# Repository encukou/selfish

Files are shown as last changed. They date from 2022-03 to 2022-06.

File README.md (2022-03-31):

# Selfish keyboard

This is an experiment.

Selfish layout for Moonlander is [here](https://configure.zsa.io/moonlander/layouts/DapMK/latest/0),
or, with some tweaks the configurator can't do, in [my QMK fork](https://github.com/encukou/qmk_firmware/blob/selfish/keyboards/moonlander/keymaps/selfish/keymap.c).

## Thanks

Thank you to Peter Lyons for sharing
[Squeezebox](https://peterlyons.com/problog/2022/01/squeezebox-keyboard-v2112/)!

## Legal stuff

Any file in this repository may be used either under the MIT licence or the
CC-BY-SA-40 licence, at your choice.
Please link to https://github.com/encukou/selfish for attribution.

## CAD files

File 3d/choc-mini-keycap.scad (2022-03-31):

OFFCENTER = 0;  // [-2.5:.1:2.5]

module _end_customizer () {}

CAP_SIZE = 12.5;
TOP_HEIGHT = 2;
CURVE_IN = 1;
STEM_BASE = 0.25;
STEM_CYLOUT = 0.2;

BORDER_W = 0.4;
BORDER_H = 0.25;

EPS = 0.001;
INF = 100;
$fn = 50;

module box (sizes, centering=[1, 1, 1], extra_negative=[0, 0, 0]) {
    translate ([
        -sizes[0]*centering[0]/2-extra_negative[0],
        -sizes[1]*centering[1]/2-extra_negative[1],
        -sizes[2]*centering[2]/2-extra_negative[2],
    ]) {
        cube ([
            sizes[0]+extra_negative[0],
            sizes[1]+extra_negative[1],
            sizes[2]+extra_negative[2],
        ]);
    }
}

module round_slab (dims, r, rd=0) {
    w = dims[0];
    h = dims[1];
    d = dims[2];
    if (r <= rd) {
        box ([w, h, d], [1, 1, 0]);
    } else {
        hull () for (x=[-1,1]) for (y=[-1,1]) scale ([x, y, 1]) {
            translate ([w/2-r, h/2-r, 0]) cylinder (d, r=r-rd);
        }
    }
}

// x^2 + diag^2 = (x+CURVE_IN)²
function cdist (base, inset) = (base^2 - inset^2) / (2 * inset);

rotate ([90, 0, 0]) union () {
    translate ([0, 0, -EPS]) difference () {
        // Main body
        hull () for (x=[-1,1]) for (y=[-1,1]) scale ([x, y, 1]) {
            fillet = TOP_HEIGHT;
            r = TOP_HEIGHT/2;
            disp = CAP_SIZE / 2 - r - r/sqrt(2);
            translate ([disp, disp, 0]) {
                rotate ([0, 0, 45]) rotate ([90, 0, 0]) {
                    rotate_extrude (angle=90) {
                        translate ([r, 0, 0]) circle (r=r);
                    }
                }
            }
        }

        // Spherical groove
        diag = sqrt(2) * CAP_SIZE/2;
        x = cdist(diag, CURVE_IN);
        intersection () {
            translate ([0, 0, x + TOP_HEIGHT]) rotate ([90, 0, 0]) {
                sphere (r=(x+CURVE_IN), $fn=300);
            }
            box ([CAP_SIZE, CAP_SIZE, TOP_HEIGHT+EPS], [1, 1, 0]);
        }
    }
    // Stem
    translate ([0, OFFCENTER, 0]) scale ([1, 1, -1]) {
        hull () {
            box ([10, 4.5, EPS], [1, 1, 0]);
            box ([10-STEM_BASE*2, 4.5-STEM_BASE*2, STEM_BASE], [1, 1, 0]);
        }
        // Stem legs
        for (x=[-1, 1]) scale ([x, 1, 1]) translate ([2.85, 0, 0]) {
            xsz = 0.95 - /* tolerance */ 0.15;
            ysz = 2.75;
            zsz = 3.9+STEM_BASE;
            w = cdist(ysz/4, STEM_CYLOUT);
            box ([xsz, ysz, zsz], [1, 1, 0]);
            for (r=[-1,1]) scale ([r, r, 1]) intersection () {
                translate ([-xsz/2, 0, 0]) box ([INF, INF, INF], [2, 1, 1]);
                translate ([w-xsz/2, ysz/4, 0]) {
                    cylinder (zsz, r=w+STEM_CYLOUT);
                }
            }
        }
    }
    // Rim
    scale ([1, 1, -1]) {
        r = TOP_HEIGHT/2;
        difference () {
            round_slab ([CAP_SIZE, CAP_SIZE, BORDER_H], r);
            hull () {
                sz = CAP_SIZE - BORDER_W;
                round_slab ([CAP_SIZE, CAP_SIZE, EPS], r, BORDER_W * 1.75);
                translate ([0, 0, BORDER_H+EPS]) {
                    round_slab ([CAP_SIZE, CAP_SIZE, EPS], r, BORDER_W);
                }
            }
        }
    }
}

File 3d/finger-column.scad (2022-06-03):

// Upper row angle
angle1 = 30;  // [20:30]
// Lower row angle
angle2 = 80;  // [20:95]
// Middle row angle (i.e. mounting tab angle)
TAB_ANGLE = 17.5; // [-60:60]

assert (angle2 - TAB_ANGLE <= 95, "Middle row angle too negative");

// Color for switch preview
SWITCH_COLOR = [.5, .3, 0];

module _end_customizer () {}

CHOC_SZ = 13.80;
CHOC_FULL_SZ = 15.00;
CHOC_H = 2.20;
WELL_ANGLES = [angle1, angle2];
CAP_SPACE = 13;
KEY_DEPTH = 10.5;

BOX_SZ_X = 15;
BOX_SZ_Y = 16;

BOTTOM_WALL = 1;

WIRE_R = .5;  // CHECK!
WIRE_N = 2;
WIRE_ORG_T = 1;
WIRE_ORG_W = 2;

DIODEW_R = 0.3;

// M3 screws
SCREW_R = 3/2;

TOL = 0.25;
RTOL = TOL/2;

INF = 22;
EPS = 0.01;

$fn = 50;

WALL_H = CHOC_H+BOTTOM_WALL;

module box (sizes, centering=[1, 1, 1], extra_negative=[0, 0, 0]) {
    translate ([
        -sizes[0]*centering[0]/2-extra_negative[0],
        -sizes[1]*centering[1]/2-extra_negative[1],
        -sizes[2]*centering[2]/2-extra_negative[2],
    ]) {
        cube ([
            sizes[0]+extra_negative[0],
            sizes[1]+extra_negative[1],
            sizes[2]+extra_negative[2],
        ]);
    }
}

module choc_well (pos=0, angle=0) translate ([0, 0, -KEY_DEPTH]) {
    difference () {
        union () {
            // Main body
            box ([BOX_SZ_X, BOX_SZ_Y-.5, WALL_H], [1, 1, 0]);
            // Connector between wells
            for (x=[-1,1]) for (y=[-1,1]) if (y == pos) scale ([x, 1, 1]) {
                rotate ([0, 90, 0]) {
                    translate ([-KEY_DEPTH, -CAP_SPACE/2*y, -BOX_SZ_X/2]) {
                        scale ([1, y, 1]) difference () {
                            $fn = $fn*5;
                            union () {
                                cylinder (BOX_SZ_X/6, r=KEY_DEPTH);
                                translate ([0, 0, BOX_SZ_X/6-EPS]) cylinder (
                                    BOX_SZ_X/6,
                                    r1=KEY_DEPTH,
                                    r2=KEY_DEPTH-WALL_H/2);
                                cylinder (BOX_SZ_Y/2, r=KEY_DEPTH-WALL_H/2);
                            }
                            translate ([0, 0, -EPS]) {
                                cylinder (BOX_SZ_Y, r=KEY_DEPTH-WALL_H);
                            }
                            box ([INF, INF, INF], [1, 0, 1], [0, 1, 0]);
                            rotate ([0, 0, -angle]) translate ([0, 1-EPS, 0]) {
                                box ([INF, INF, INF], [1, 2, 1]);
                            }
                        }
                    }
                }
            }
        }
        // Main body cutout
        translate ([0, 0, BOTTOM_WALL]) {
            box ([CHOC_SZ+TOL, CHOC_SZ+TOL, INF], [1, 1, 0]);
        }
        // Cutout for middle plastic pin of the keyswitch
        translate ([0, 0, -1]) cylinder(INF, r=3.20/2+RTOL);
        // Cutout for side plastic pins
        for (y=[-1,1]) translate ([0, y*11/2, -1]) cylinder(INF, r=1.80/2+RTOL);
        // Contact pins of the keyswitch
        for (xy=[[5.90, 0], [3.80, -5]]) translate ([xy[0], xy[1], -EPS]) {
            cylinder(BOTTOM_WALL+1+EPS, r=2.90/2+RTOL);
            %union () {
                box ([4.55, 5, 1.85], [1,1,2]);
                translate ([0, 0, 0]) box ([1.68, 5+2*1.6, 1.85], [1,1,2]);
            }
        }
        /* // LED hole
        translate ([-4.70, 0, -1]) box ([2.8+TOL, 3.2+TOL, INF]);
        translate ([-4.70, 0, -1]) box ([2.8+TOL, 5.9+TOL, 1+BOTTOM_WALL-.5], [1, 1, 0]);
        //*/
    }
    //%choc_skeleton ();
    // Clip for wires
    positions = pos == 1 ? [0] : [BOX_SZ_Y/2-WIRE_ORG_W];
    scale ([1, 1, -1]) for (y=positions) translate ([-BOX_SZ_X/2, y, 0]) {
        difference () {
            hull () {
                box ([WIRE_R*2*(WIRE_N-1), WIRE_ORG_W, WIRE_R*2+WIRE_ORG_T], [0, 1, 0]);
                box ([WIRE_R*2*(WIRE_N+1)+WIRE_ORG_T+TOL, WIRE_ORG_W, EPS], [0, 1, 0]);
                translate ([WIRE_R*2*(WIRE_N-.5), -WIRE_ORG_W/2, WIRE_R]) {
                    rotate (-90, [1, 0, 0]) intersection () {
                        cylinder (WIRE_ORG_W, r=WIRE_R+WIRE_ORG_T+TOL);
                        box ([INF, INF, INF], [1, 2, 1]);
                    }
                }
            }
            for (x=[-1:WIRE_N-1]) translate ([(x*2+1)*WIRE_R, -INF/2, WIRE_R]) {
                rotate (-90, [1, 0, 0]) cylinder (INF, r=WIRE_R+RTOL);
            }
            translate ([0, 0, WIRE_R]) box ([WIRE_R*2*(WIRE_N-.5), WIRE_ORG_W*2, WIRE_R*2-TOL/2], [0, 1, 1], [EPS, 0, 0]);
        }
    }
    // Clip for row wire
    scale ([1, 1, -1]) translate ([1.6, 3.2, 0]) {
        difference () {
            hull () {
                box ([WIRE_R*2+WIRE_ORG_T, WIRE_R*2+WIRE_ORG_T*3, EPS], [0, 1, 0]);
                box ([WIRE_ORG_T, WIRE_R*2+WIRE_ORG_T*2, WIRE_R*3+TOL], [2, 1, 0]);
            }
            translate ([-INF/2, 0, WIRE_R+TOL]) rotate (90, [0, 1, 0]){
                hull () {
                    cylinder (INF, r=WIRE_R+RTOL);
                    translate ([-WIRE_R*2, 0, 0]) cylinder (INF, r=WIRE_R-RTOL);
                }
            }
        }
    }
    // Clip for diode wire
    for (y=[-1,1]) if (pos != 1 || y==1) scale ([1, 1, -1]) {
        r = pos == 1 ? angle : 0;
        scale ([1, y, 1]) translate ([-2, (-BOX_SZ_Y/2+1), -.5]) rotate ([r, 0, 0]) difference () {
            translate ([0, 0, 0]) hull () {
                rotate ([0, 90, 0]) translate ([0, 0, -1]) cylinder (4, r=1/2);
                translate ([-1, 0, 0]) box ([WIRE_ORG_T+DIODEW_R+2, 1, EPS], [0, 1, 0]);
                translate ([-1, 0, WIRE_ORG_T+DIODEW_R+TOL+.5]) box ([1.5, 1, EPS], [0, 1, 0]);
            }
            translate ([0, 0, 1]) hull () {
                translate ([0, 1, DIODEW_R-.5]) rotate (90, [1, 0, 0]) cylinder (INF, r=DIODEW_R+RTOL);
                translate ([-1, 1, DIODEW_R-.5]) rotate (90, [1, 0, 0]) cylinder (INF, r=DIODEW_R);
            }
        }
    }
}

module choc_skeleton () {
    translate ([0, 0, BOTTOM_WALL+5]) color (SWITCH_COLOR) {
        difference () {
            union () {
                box ([3, 3, 3.00], [0, 1, 0]);
                box ([4.5, 10, 3.00], [1, 1, 0]);
            }
            for (y=[-1,1]) translate ([0, y*5.70/2, -1]) {
                box ([3.00, 1.20, INF]);
            }
        }
    }
    translate ([0, 0, BOTTOM_WALL+2.20]) {
        box ([CHOC_FULL_SZ, CHOC_FULL_SZ, 0.80], [1, 1, 0]);
    }
    translate ([0, 0, BOTTOM_WALL+8]) {
        rotate (90, [0, 0, 1]) import ("cap-Body.stl");
    }
}

module mount_pad (pos, angle) scale ([1, pos, -1]) {
    prot = 2;
    ang = angle-TAB_ANGLE*pos;
    hole_dist = 3;
    hole_r = 3/2-TOL;
    difference () {
        box ([BOX_SZ_X, INF, WALL_H], [1, 0, 0]);
        hull () {
            box ([BOX_SZ_X*2/6, INF, INF], [1, 0, 0], [0, 0, -1]);
            translate ([0, 0, WALL_H-1]) box ([BOX_SZ_X*4/6, INF, INF], [1, 0, 0], [0, 0, -1]);
        }
        translate ([0, prot, 0]) rotate ([ang, 0, 0]) box ([INF, INF*3, INF*3], [1, 1, 2]);
    }
    translate ([0, prot, 0]) rotate ([ang-90, 0, 0]) {
        top_prot = WALL_H/sin(ang);
        difference () {
            hull () {
                box ([BOX_SZ_X, 1, top_prot], [1, 2, 0]);
                translate ([0, 0, top_prot+hole_dist]) {
                    rotate ([90, 0, 0]) cylinder (1, r=hole_dist);
                }
            }
            translate ([0, EPS, top_prot+hole_dist]) {
                rotate ([90, 0, 0]) cylinder (INF, r=hole_r);
            }
        }
    }
}

rotate ([-TAB_ANGLE, 0, 0]) for (pos=[-1, 0, 1]) translate ([0, CAP_SPACE/2*pos, 0]) {
    angle = (pos == -1) ? WELL_ANGLES[0]
          : (pos == 1) ? WELL_ANGLES[1]
          : 0;
    rotate ([angle*pos, 0, 0]) {
        translate ([0, CAP_SPACE/2*pos, 0]) {
            choc_well (pos=pos, angle=angle);
        }
        if (pos != 0) translate ([0, (CAP_SPACE+1)*pos, -KEY_DEPTH+WALL_H]) {
            mount_pad (pos=pos, angle=angle);
        }
    }
}

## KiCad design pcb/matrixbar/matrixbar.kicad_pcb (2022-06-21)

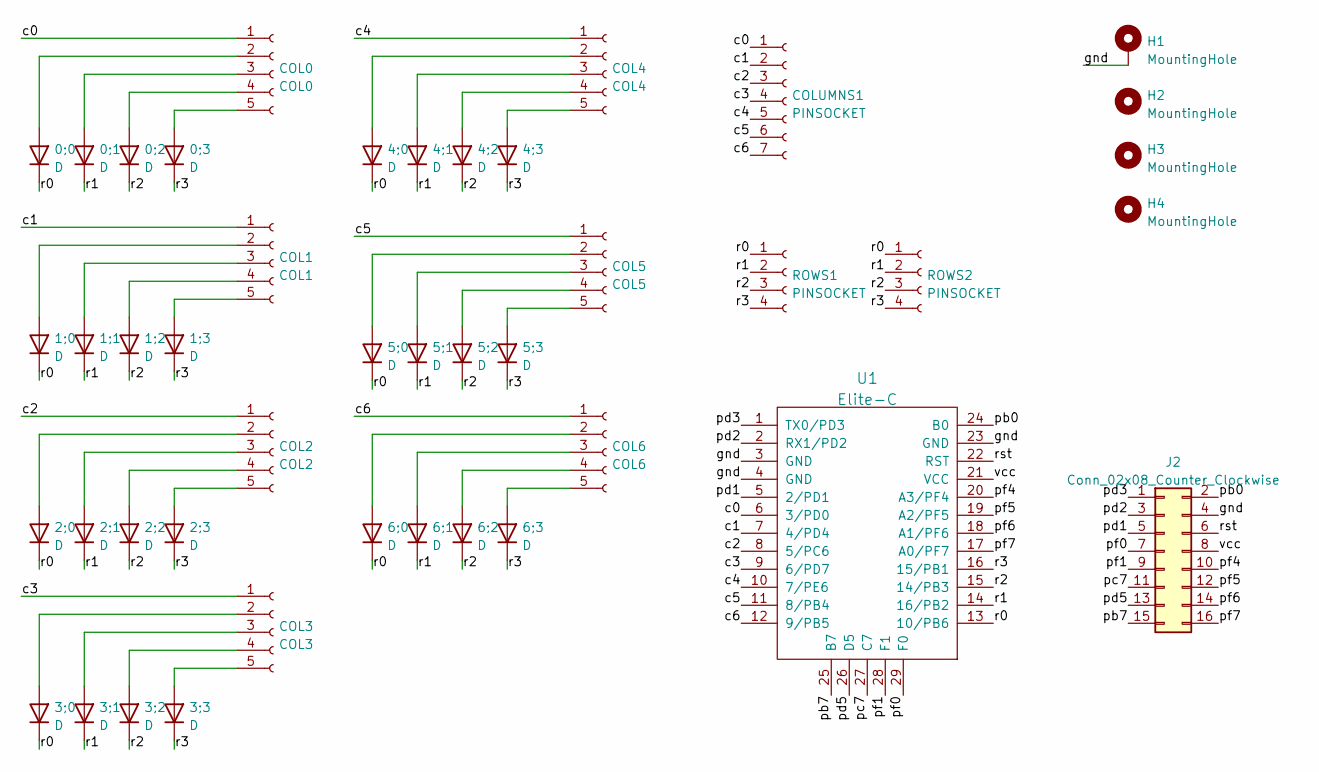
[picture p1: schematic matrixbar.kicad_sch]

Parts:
0;0, 0;1, 0;2, 0;3, 1;0, 1;1, 1;2, 1;3, 2;0, 2;1, 2;2, 2;3, 3;0, 3;1, 3;2, 3;3, 4;0, 4;1, 4;2, 4;3, 5;0, 5;1, 5;2, 5;3, 6;0, 6;1, 6;2, 6;3: D; Diode
COL0: COL0; PinHeader_1x05_P2.54mm_Vertical
COL1: COL1; PinHeader_1x05_P2.54mm_Vertical
COL2: COL2; PinHeader_1x05_P2.54mm_Vertical
COL3: COL3; PinHeader_1x05_P2.54mm_Vertical
COL4: COL4; PinHeader_1x05_P2.54mm_Vertical
COL5: COL5; PinHeader_1x05_P2.54mm_Vertical
COL6: COL6; PinHeader_1x05_P2.54mm_Vertical
COLUMNS1: PINSOCKET; PinHeader_1x07_P2.54mm_Vertical
H1: MountingHole; MountingHole_2.2mm_M2_DIN965_Pad
H2, H3, H4: MountingHole
J2: Conn_02x08_Counter_Clockwise; PinSocket_2x08_P2.54mm_Bespoke
ROWS1, ROWS2: PINSOCKET; PinSocket_1x04_P2.54mm_Vertical_LongPads
U1: Elite-C

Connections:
/c0: COL0.1, COLUMNS1.1, U1.6 (3/PD0)
/c1: COL1.1, COLUMNS1.2, U1.7 (4/PD4)
/c2: COL2.1, COLUMNS1.3, U1.8 (5/PC6)
/c3: COL3.1, COLUMNS1.4, U1.9 (6/PD7)
/c4: COL4.1, COLUMNS1.5, U1.10 (7/PE6)
/c5: COL5.1, COLUMNS1.6, U1.11 (8/PB4)
/c6: COL6.1, COLUMNS1.7, U1.12 (9/PB5)
/gnd: H1.1, J2.4, U1.3 (GND), U1.4 (GND), U1.23 (GND)
/pb0: J2.2, U1.24 (B0)
/pb7: J2.15, U1.25 (B7)
/pc7: J2.11, U1.27 (C7)
/pd1: J2.5, U1.5 (2/PD1)
/pd2: J2.3, U1.2 (RX1/PD2)
/pd3: J2.1, U1.1 (TX0/PD3)
/pd5: J2.13, U1.26 (D5)
/pf0: J2.7, U1.29 (F0)
/pf1: J2.9, U1.28 (F1)
/pf4: J2.10, U1.20 (A3/PF4)
/pf5: J2.12, U1.19 (A2/PF5)
/pf6: J2.14, U1.18 (A1/PF6)
/pf7: J2.16, U1.17 (A0/PF7)
/r0: 0;0.1 (K), 1;0.1 (K), 2;0.1 (K), 3;0.1 (K), 4;0.1 (K), 5;0.1 (K), 6;0.1 (K), ROWS1.1, ROWS2.1, U1.13 (10/PB6)
/r1: 0;1.1 (K), 1;1.1 (K), 2;1.1 (K), 3;1.1 (K), 4;1.1 (K), 5;1.1 (K), 6;1.1 (K), ROWS1.2, ROWS2.2, U1.14 (16/PB2)
/r2: 0;2.1 (K), 1;2.1 (K), 2;2.1 (K), 3;2.1 (K), 4;2.1 (K), 5;2.1 (K), 6;2.1 (K), ROWS1.3, ROWS2.3, U1.15 (14/PB3)
/r3: 0;3.1 (K), 1;3.1 (K), 2;3.1 (K), 3;3.1 (K), 4;3.1 (K), 5;3.1 (K), 6;3.1 (K), ROWS1.4, ROWS2.4, U1.16 (15/PB1)
/rst: J2.6, U1.22 (RST)
/vcc: J2.8, U1.21 (VCC)
unnamed: 0;0.2 (A), COL0.2
unnamed: 0;1.2 (A), COL0.3
unnamed: 0;2.2 (A), COL0.4
unnamed: 0;3.2 (A), COL0.5
unnamed: 1;0.2 (A), COL1.2
unnamed: 1;1.2 (A), COL1.3
unnamed: 1;2.2 (A), COL1.4
unnamed: 1;3.2 (A), COL1.5
unnamed: 2;0.2 (A), COL2.2
unnamed: 2;1.2 (A), COL2.3
unnamed: 2;2.2 (A), COL2.4
unnamed: 2;3.2 (A), COL2.5
unnamed: 3;0.2 (A), COL3.2
unnamed: 3;1.2 (A), COL3.3
unnamed: 3;2.2 (A), COL3.4
unnamed: 3;3.2 (A), COL3.5
unnamed: 4;0.2 (A), COL4.2
unnamed: 4;1.2 (A), COL4.3
unnamed: 4;2.2 (A), COL4.4
unnamed: 4;3.2 (A), COL4.5
unnamed: 5;0.2 (A), COL5.2
unnamed: 5;1.2 (A), COL5.3
unnamed: 5;2.2 (A), COL5.4
unnamed: 5;3.2 (A), COL5.5
unnamed: 6;0.2 (A), COL6.2
unnamed: 6;1.2 (A), COL6.3
unnamed: 6;2.2 (A), COL6.4
unnamed: 6;3.2 (A), COL6.5

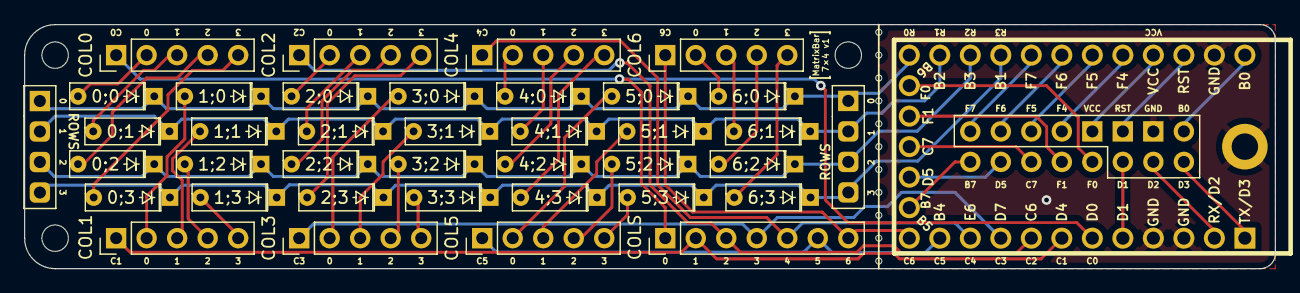
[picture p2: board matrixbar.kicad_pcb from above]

Board: 2 copper layers, 104.1 x 20.3 mm, 44 parts (1 on the bottom side), 55 nets.

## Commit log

2022-02-18 Add a Choc keyswitch well and an experimental keycap
    [cap.FCStd, switch-well.scad]
2022-03-10 Refine cap & join 3 keywells
    [cap.FCStd, switch-well.scad]
2022-03-10 Add wire clips
    [switch-well.scad]
2022-03-10 Add diode grooves
    [switch-well.scad]
2022-03-10 Improve parametrization & remove unnecessary parts from end wells
    [switch-well.scad]
2022-03-10 Add mount pads
    [switch-well.scad]
2022-03-10 Set smaller row spacing
    [switch-well.scad]
2022-03-31 Add Squeezebox-style "saxophone" bottom row angle
    [switch-well.scad]
2022-03-31 Rename finger column model
    [finger-column.scad]
2022-03-31 Replace FreeCAD keycap model with an OpenSCAD one
    [cap.FCStd, choc-mini-keycap.scad]
2022-04-05 Adjust connectors so the middle keyswitch can fit
    [finger-column.scad]
2022-04-06 Redesign the mounting pads
    [finger-column.scad]
2022-06-03 Remove unused variables
    [finger-column.scad]
2022-06-16 Add KiCAD PCB for a diode/connector bar for a Squeezebox-style keyboard
    [squeezebar.kicad_pcb, squeezebar.kicad_sch]
2022-06-16 Add mounting holes & extra side connectors
    [squeezebar.kicad_pcb, squeezebar.kicad_sch]
2022-06-17 squeezebar: Switch to a more regular layout (WIP)
    [squeezebar.kicad_pcb, squeezebar.kicad_sch]
2022-06-17 Squeezebar: New layout
    [squeezebar.kicad_pcb, squeezebar.kicad_sch]
2022-06-18 Squeezebar (Matrix Daughterboard): Compact layout
    [squeezebar.kicad_pcb]
2022-06-18 Add numbers for mounting holes
    [squeezebar.kicad_pcb]
2022-06-19 Squeezebar PCB: Add MCU. It's no longer a daughterboard...
    [squeezebar.kicad_pcb, squeezebar.kicad_sch]
2022-06-20 MatrixBar: Use Pro Micro pins for the rows/cols
    [squeezebar.kicad_pcb, squeezebar.kicad_sch]
2022-06-20 Round corners
    [squeezebar.kicad_pcb]
2022-06-21 Rename to "MatrixBar"
    [matrixbar.kicad_pcb, matrixbar.kicad_sch]
2022-06-21 Add .gitignore for KiCad PCBs
